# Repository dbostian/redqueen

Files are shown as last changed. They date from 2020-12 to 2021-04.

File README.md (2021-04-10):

# Red Queen
## Split Mechanical Keyboard inspired by TGR's Alice

example

example

example

## Project Structure
/3d_files - STL and STEP files for CNC + 3d Printing

/qmk - Firmware folder for QMK

/raw_data - Data from [keyboard-layout-editor.com](http://www.keyboard-layout-editor.com/) and [kbfirmware.com](https://kbfirmware.com/)

## Components
- [ ] 1x Left Plate (CNC or Print *see plate notes below*)
- [ ] 1x Right Plate (CNC or Print)
- [ ] 1x Left Shell (Print)
- [ ] 1x Right Shell (Print)
- [ ] 1x Left Pro Micro Tray (Print)
- [ ] 1x Right Pro Micro Tray (Print)
- [ ] 2x I/O Shield (Print)
- [ ] 8x Leg (Print)
- [ ] 8x Splined Insert (Print)

## Hardware
- [ ] 64x Switches (cherry compatable)
- [ ] 64x 1N4148 Diodes
- [ ] 2x Pro Micro
- [ ] 2x TRRS Jack
- [ ] 5x 2u Costar Stabilizers
- [ ] 3x Resistors (2x 4.7k ohm for I2C pullups, 1x 150 ohm for led)
- [ ] 64x Amoeba PCB (optional)
- [ ] 1x LED (caps lock, optional)
- [ ] 21x M3 x 8mm Countersunk Machine Screw
- [ ] 8x M3x16 Thumbscrew
- [ ] 8x M3 Nut
- [ ] 8x 6.5mm ID Rubber Cap (feet for tenting legs)
- [ ] 8x M3 Washer
- [ ] 8x Adhesive Rubber Foot (optional)
- [ ] Wire

## Tools / Misc
- [ ] CNC Router (optional)
- [ ] 3d Printer
- [ ] Soldering Iron + Solder
- [ ] Multimeter
- [ ] Wire Cutters / Strippers / Flush Cutters
- [ ] Hex Drivers
- [ ] M3 Tap

## Plate Notes
The switch plates are routed out of 1/16" (1.58 mm) 6061 aluminum, using a 1/8" (3.175mm) end mill. STEP files are included for the plates in addition to STLs. These parts were designed around a hobbyist cnc router, hence the dogboned corners in the switch holes, and the rounded corners for the stabilizers.

example

If you are 3D printing the plates, use the included **left_plate_v2.stl** and **right_plate_v2.stl** files. These are 3mm thick around the switch holes for stiffness, but undercut at 45 degrees so that you can still snap a switch into the hole.

example

## Printing Notes
Print at 0.2mm layer height. To recreate the embossed Red Queen in the bottom of the left shell, use the color changing feature in your slicing software. Print one layer of black, then change filament for one layer of red, and then change back to print the the remainder in black. I did this for both halves.

example

You will need to add supports for the i/o opening in the back of the shells. I suggest using a support enforcer, which will save you cleaning up the holes for the legs.

example

## Wiring
Rows are wired to pins C6, D7, E6, B4, B5. Columns are wired to F4, F5, F6, F7, B1, B3, B2, B6. The left hand side has only seven columns, and does not use the F4 pin.

example

I mounted an LED under the caps lock keycap. It is wired to D4.

example

I used Amoeba single-key PCBS to make wiring easier/neater.

example

Insert the TRRS jack into the MCU tray before wiring. Remember to flush trim the leads on the bottom of the Pro Micro before sliding it into the holder.

example

## Assembly
Tap appropriate holes in the shells and MCU trays to M3. Insert M3 nuts into the corners of each shell, and press all the way down to seat. Attach the MCU tray along with the I/O Shield to the back of the shell. Arrange wires neatly, and attach the plate to shell with M3x8mm countersunk screws - use caution to not overtighten and strip the threads in the printed shell.

The inserts for the tenting legs can be rotated to six major positions, each with thirteen minor positions. This should provide decent adjustability. There's a notch on the insert to help with orientation.

example

## Firmware
I used [QMK firmware](https://qmk.fm/) - there's an included keyboards folder for compiling/flashing your own keyboard.

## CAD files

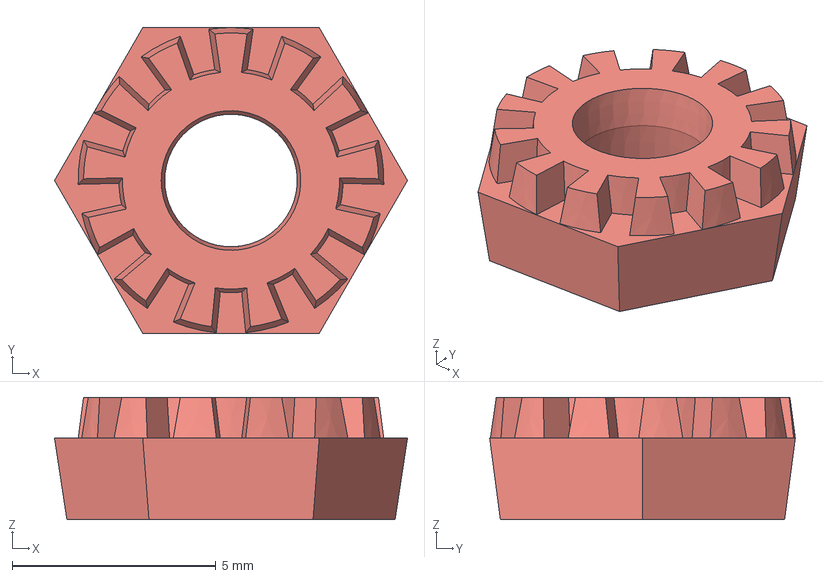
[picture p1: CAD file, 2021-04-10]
3d_files/step/leg_splined_insert.step
8.66 x 7.50 x 3.00 mm

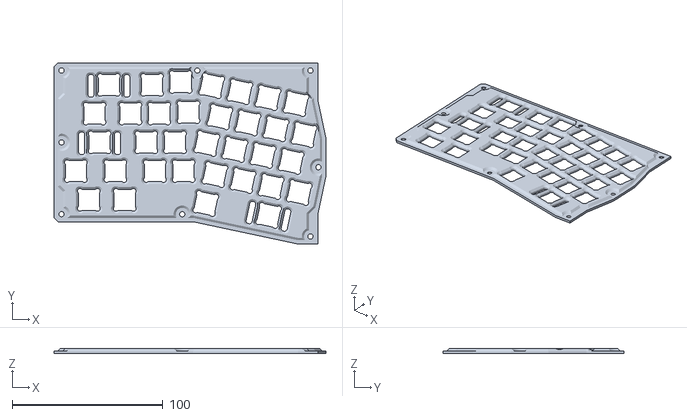
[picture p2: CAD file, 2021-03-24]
3d_files/stls/right_plate_v2.stl
180.3 x 120.0 x 3.17

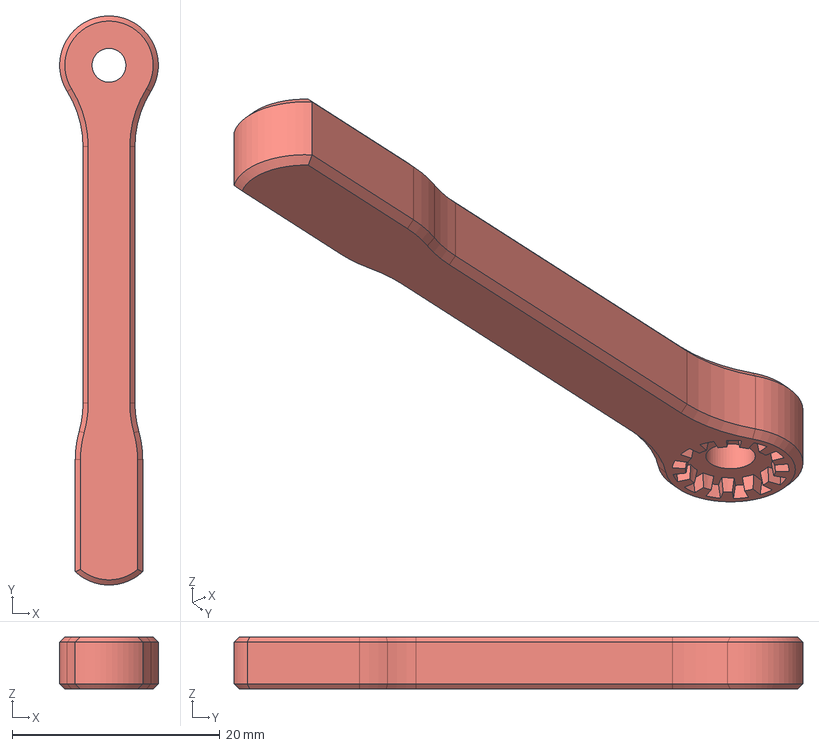
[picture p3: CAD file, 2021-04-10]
3d_files/step/leg.step
9.49 x 54.7 x 5.00 mm

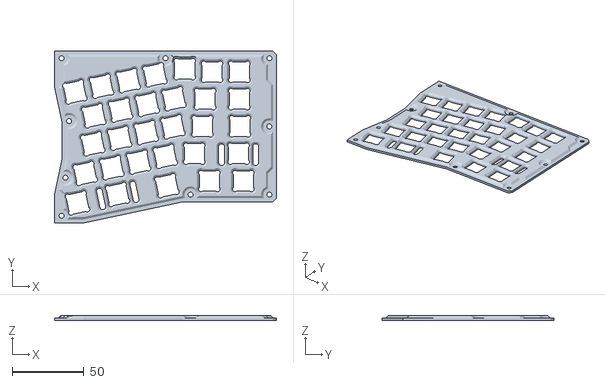
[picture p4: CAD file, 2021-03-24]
3d_files/stls/left_plate_v2.stl
155.0 x 120.0 x 3.17

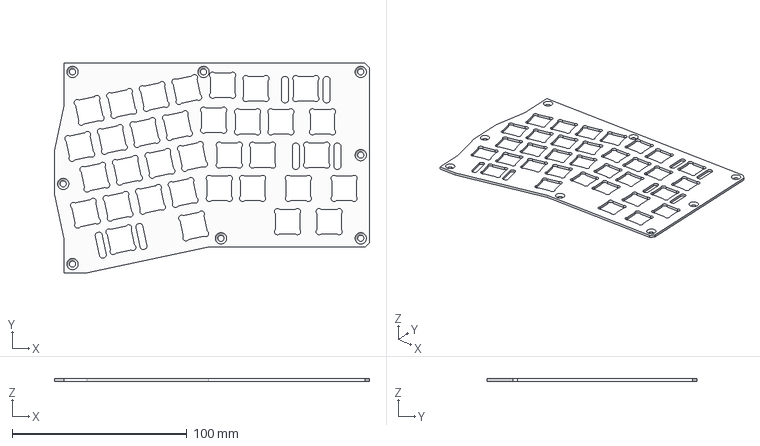
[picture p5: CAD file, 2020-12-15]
3d_files/step/right_plate.step
180.3 x 120.0 x 1.67 mm

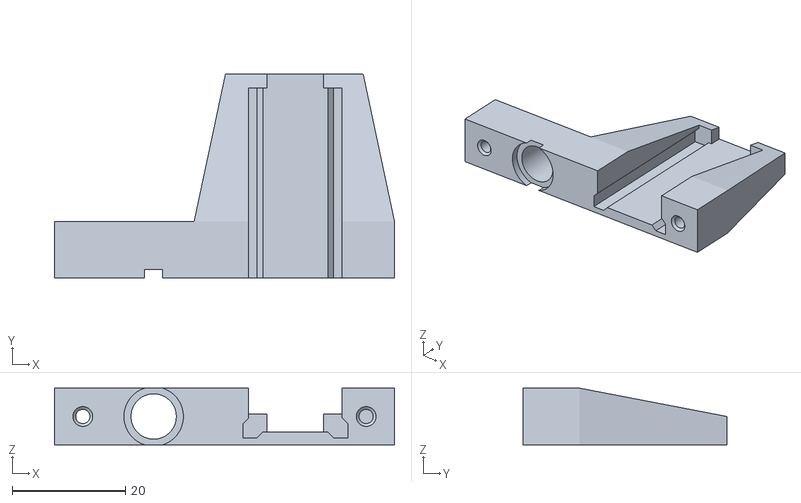
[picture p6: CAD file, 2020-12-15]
3d_files/stls/left_pro_micro_tray.stl
60.0 x 36.0 x 10.0

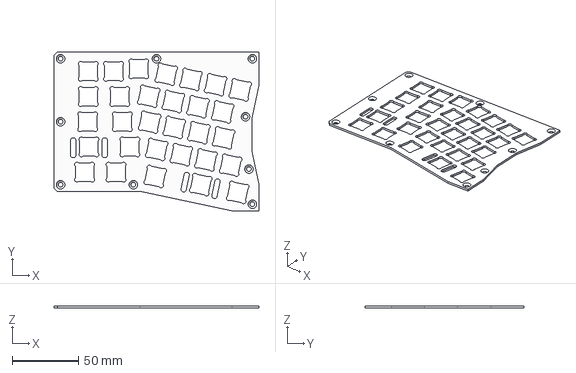
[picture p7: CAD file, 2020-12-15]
3d_files/step/left_plate.step
155.0 x 120.0 x 1.67 mm

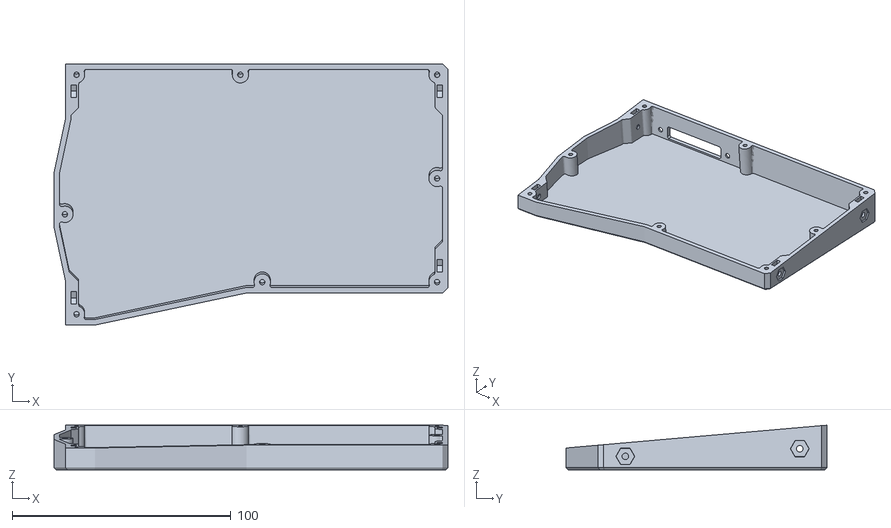
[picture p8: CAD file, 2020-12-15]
3d_files/stls/right_shell.stl
180.3 x 119.5 x 20.5

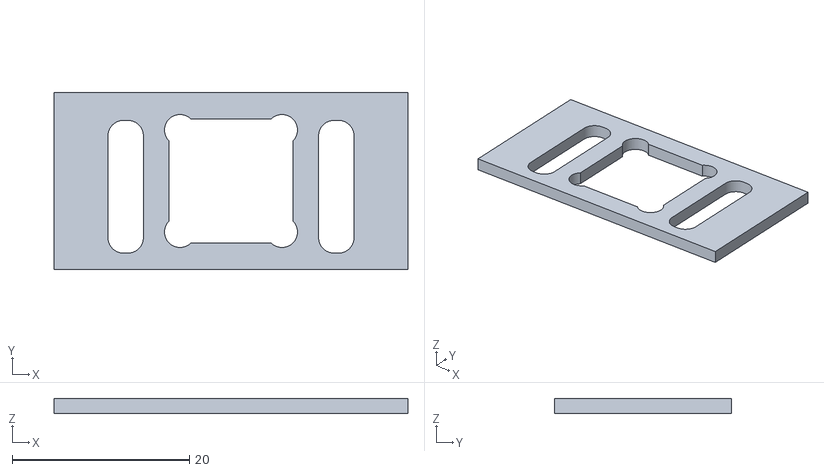
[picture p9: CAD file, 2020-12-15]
3d_files/stls/test_plate.stl
40.0 x 20.0 x 1.67

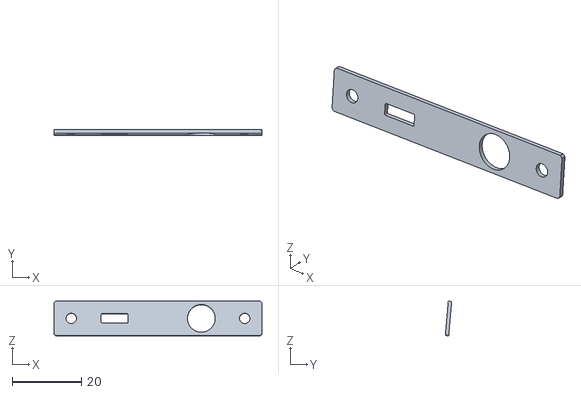
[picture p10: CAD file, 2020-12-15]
3d_files/stls/io_shield.stl
60.0 x 1.87 x 10.0

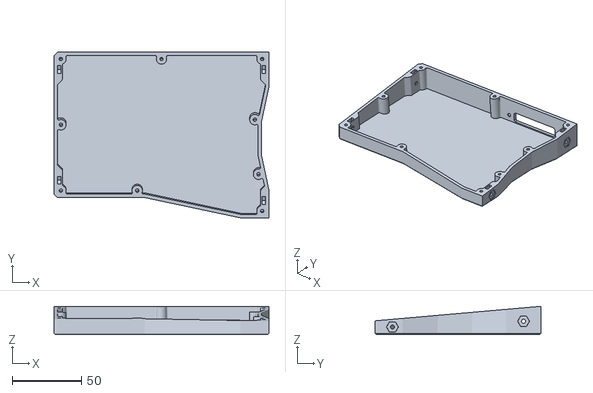
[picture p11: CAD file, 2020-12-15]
3d_files/stls/left_shell.stl
155.0 x 119.5 x 20.5

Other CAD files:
3d_files/stls/right_pro_micro_tray.stl
3d_files/stls/left_plate.stl
3d_files/stls/leg.stl
3d_files/stls/leg_splined_insert.stl
3d_files/stls/right_plate.stl

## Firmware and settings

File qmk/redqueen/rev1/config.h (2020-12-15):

/*
Copyright 2020 Dan Bostian <dbostian@gmail.com>

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
You should have received a copy of the GNU General Public License
along with this program.  If not, see <http://www.gnu.org/licenses/>.
*/

#pragma once

#include "config_common.h"

/* USB Device descriptor parameter */
#define VENDOR_ID       0xFEED
#define PRODUCT_ID      0x0000
#define DEVICE_VER      0x0001
#define MANUFACTURER    Bostian
#define PRODUCT         The Red Queen
#define DESCRIPTION     Custom Split Alice-like Keyboard

/* key matrix size */
// Rows are doubled-up
#define MATRIX_ROWS 10
#define MATRIX_COLS 8

// wiring of each half
#define MATRIX_ROW_PINS { C6, D7, E6, B4, B5 }
#define MATRIX_COL_PINS { F4, F5, F6, F7, B1, B3, B2, B6 }
// #define MATRIX_COL_PINS { B6, B2, B3, B1, F7, F6, F5} //uncomment this line and comment line above if you need to reverse left-to-right key order

#define LED_CAPS_LOCK_PIN D4

/* COL2ROW or ROW2COL */
#define DIODE_DIRECTION COL2ROW

/* define if matrix has ghost */
//#define MATRIX_HAS_GHOST

/* number of backlight levels */
// #define BACKLIGHT_LEVELS 3

/* Set 0 if debouncing isn't needed */
#define DEBOUNCE 5

/* serial.c configuration for split keyboard */
#define SOFT_SERIAL_PIN D0


/* mouse keys */
#define MOUSEKEY_INTERVAL 16
#define MOUSEKEY_DELAY 0
#define MOUSEKEY_TIME_TO_MAX 60
#define MOUSEKEY_MAX_SPEED 7
#define MOUSEKEY_WHEEL_DELAY 0


/* Mechanical locking support. Use KC_LCAP, KC_LNUM or KC_LSCR instead in keymap */
//#define LOCKING_SUPPORT_ENABLE
/* Locking resynchronize hack */
//#define LOCKING_RESYNC_ENABLE

/* ws2812 RGB LED */
//#define RGB_DI_PIN D3

//#define RGBLED_NUM 14    // Number of LEDs

//#define RGBLIGHT_SPLIT   // sync LEDs between RIGHT and LEFT hand

/*
 * Feature disable options
 *  These options are also useful to firmware size reduction.
 */

/* disable debug print */
// #define NO_DEBUG

/* disable print */
// #define NO_PRINT

/* disable action features */
//#define NO_ACTION_LAYER
//#define NO_ACTION_TAPPING
//#define NO_ACTION_ONESHOT
//#define NO_ACTION_MACRO
//#define NO_ACTION_FUNCTION

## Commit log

2020-12-15 Added README
    [io_shield.stl, left_plate.step, left_plate.stl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]
2021-03-24 Added 3d-printalbe plates
    [left_plate_v2.stl, right_plate_v2.stl]
2021-04-10 Added STEP files for legs t
    [leg.step, leg_splined_insert.step]

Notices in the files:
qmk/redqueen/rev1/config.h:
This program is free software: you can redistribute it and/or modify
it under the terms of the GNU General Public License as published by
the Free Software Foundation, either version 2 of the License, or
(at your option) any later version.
